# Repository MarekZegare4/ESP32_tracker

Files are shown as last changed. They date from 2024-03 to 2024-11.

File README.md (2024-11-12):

## Antenna tracker based on ESP32 microcontroller

This project focuses on the development of an antenna tracker with some ground station functionalities. Developed in platformio with Arduino framework. Based on [mLRS](https://github.com/olliw42/mLRS) project for MAVLink telemetry data.

### Contents of the repository
- `src` - source code of the project
- `schematic` - schematics and PCB design files
- `matlab_scripts` - magnetometer calibration routine

### Current features
- Tracking based on built-in GNSS receiver data and telemetry data from UAV
- 360° continuous rotation in vertical axis
- WiFi/BT/USB telemetry bridge
- Implemented magnetometer with calibration routine
### To be implemented
- GUI for configuration and monitoring on built-in display
- IMU pan and tilt stabilization
-
-
- More telemetry protocols

---

## Current PCB design
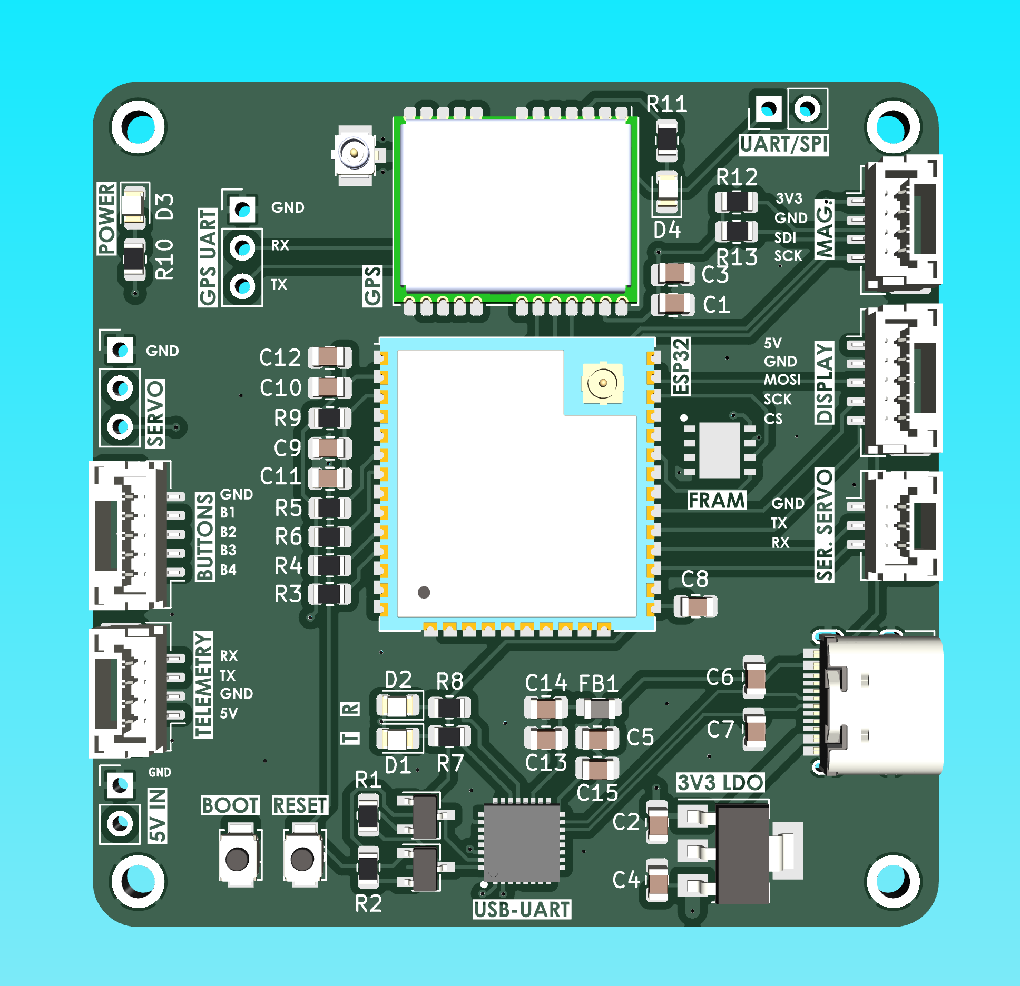
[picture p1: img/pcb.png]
PCB


## Current mechanical design
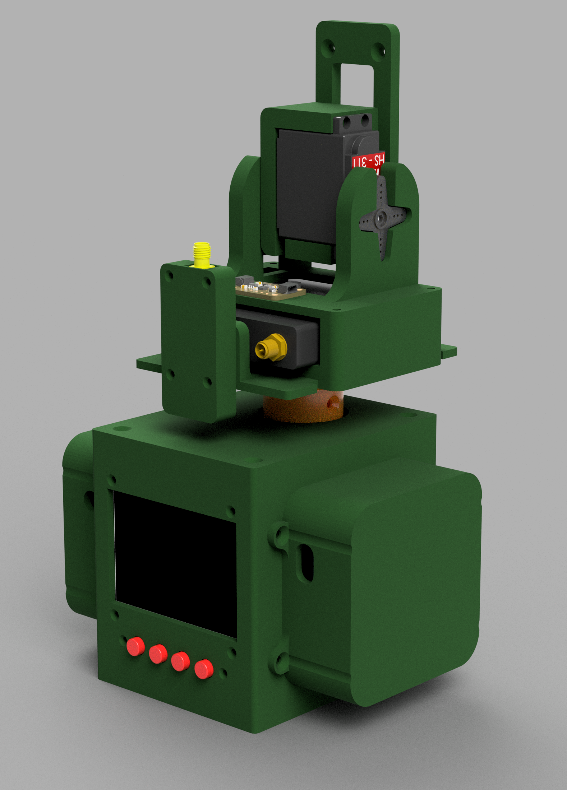
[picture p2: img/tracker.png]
Mechanical


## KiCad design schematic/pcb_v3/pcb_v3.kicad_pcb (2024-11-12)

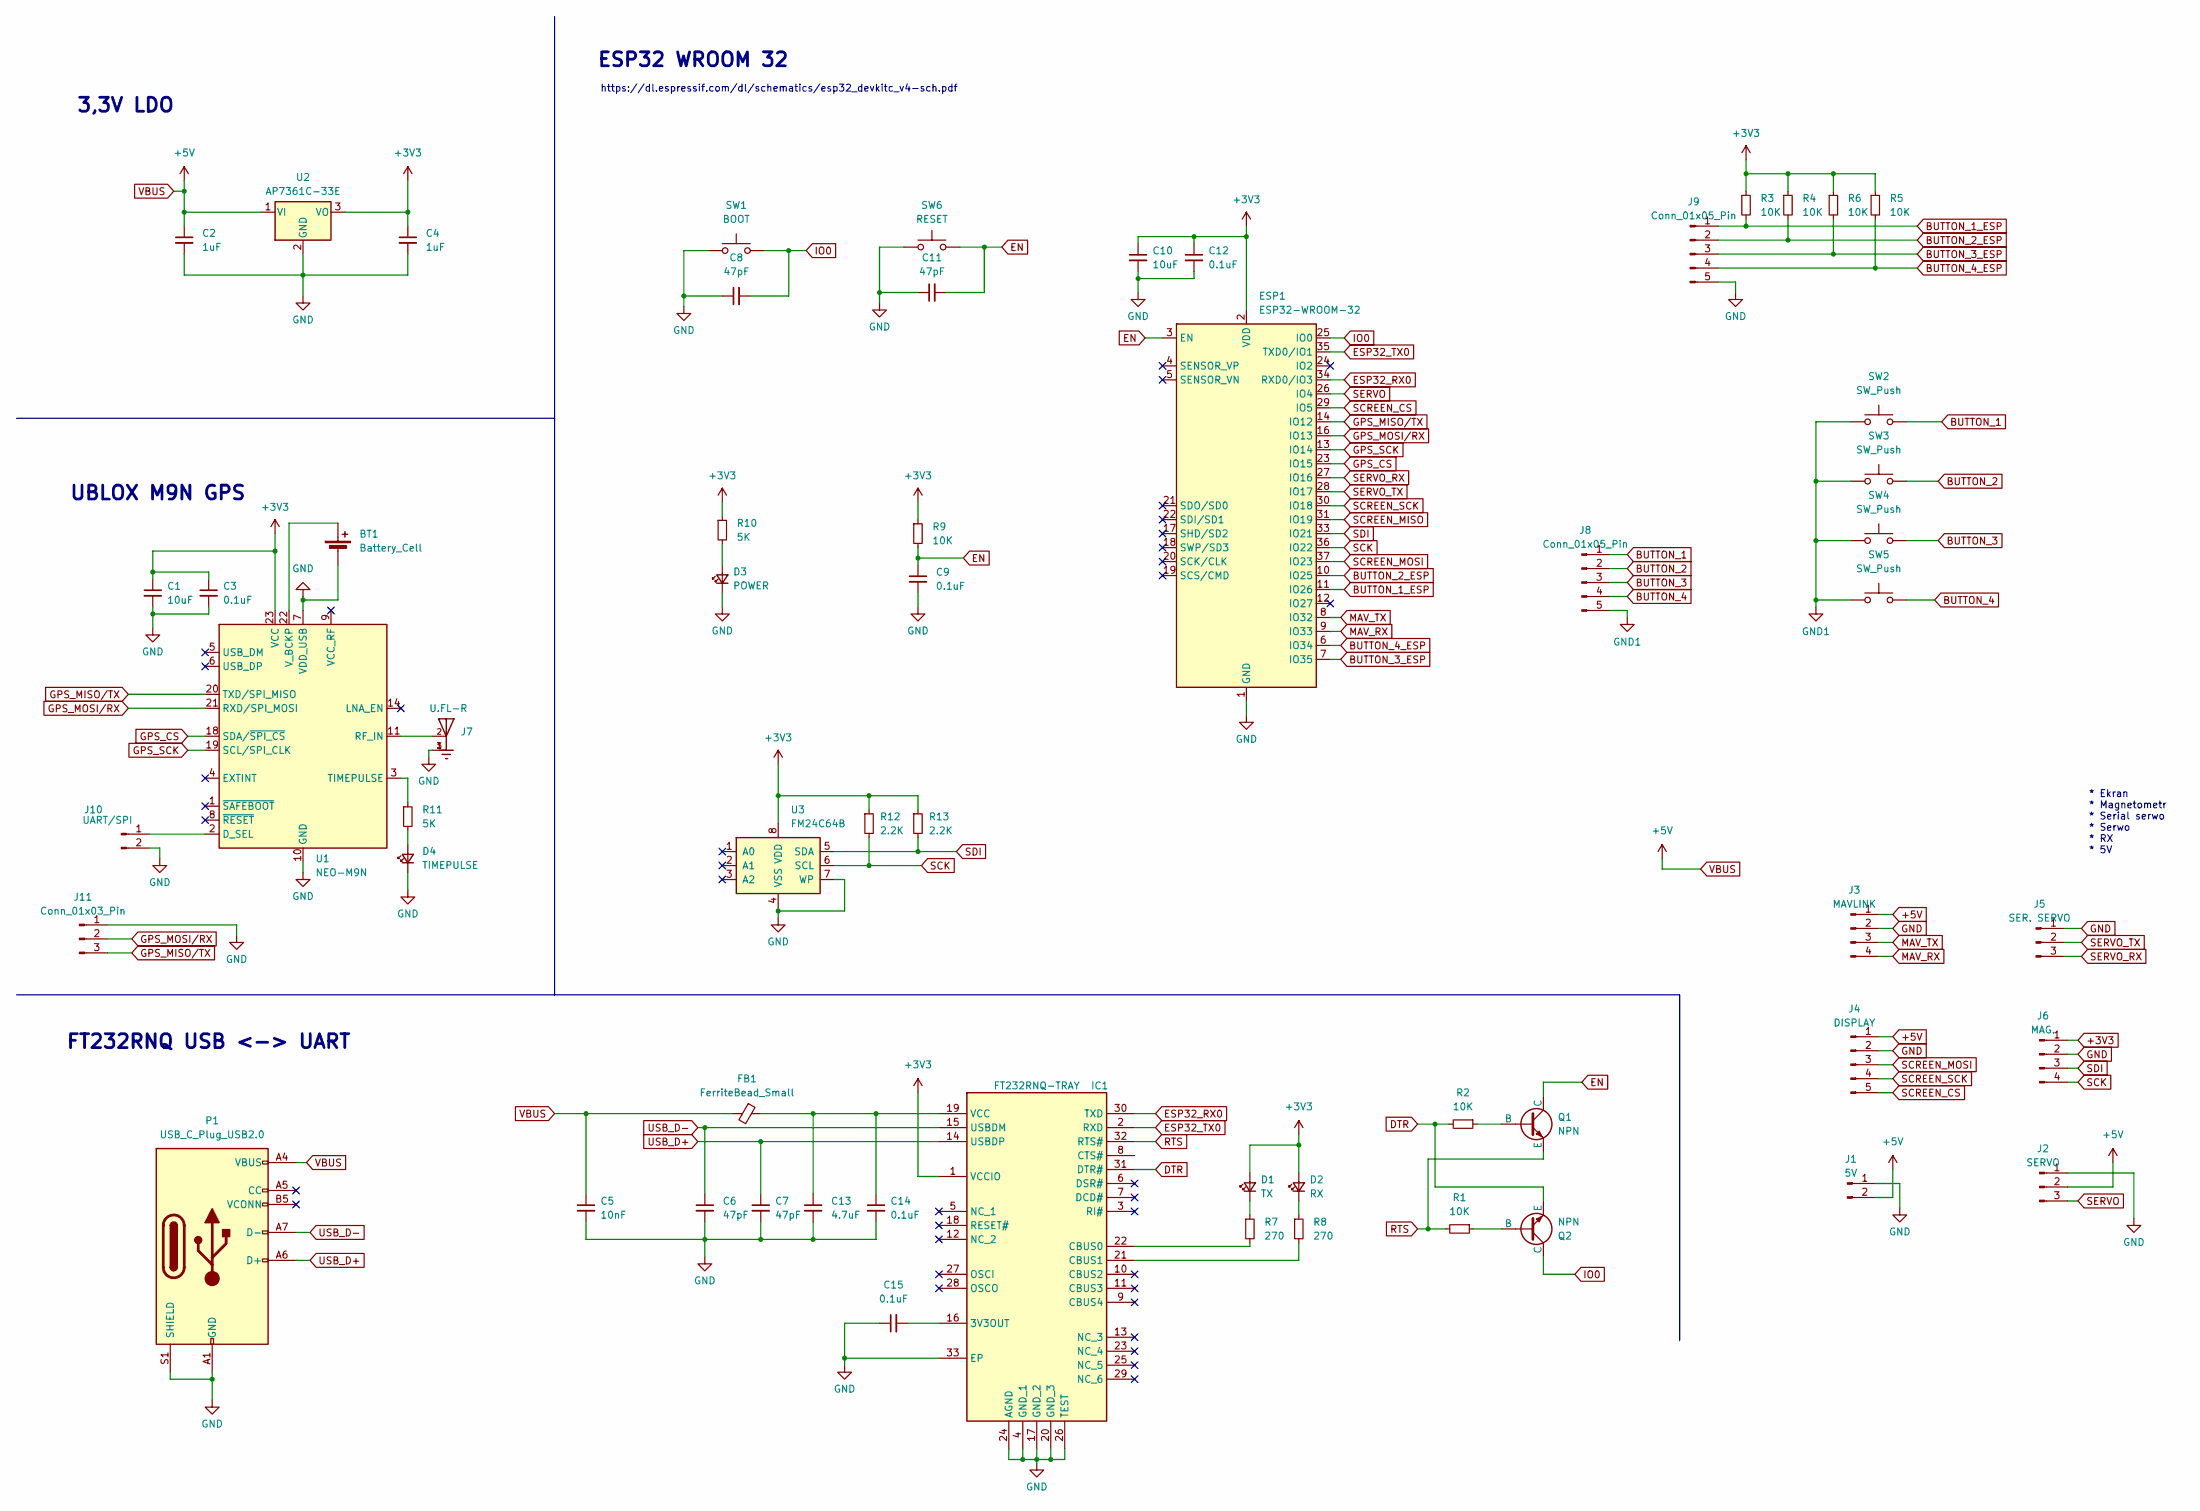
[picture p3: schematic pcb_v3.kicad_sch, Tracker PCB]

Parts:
BT1: Battery_Cell; BatteryHolder_Keystone_1060_1x2032
C1, C10: 10uF; C_0805_2012Metric
C2, C4: 1uF; C_0805_2012Metric
C3, C9, C12, C14, C15: 0.1uF; C_0805_2012Metric
C5: 10nF; C_0805_2012Metric
C6, C7, C8, C11: 47pF; C_0805_2012Metric
C13: 4.7uF; C_0805_2012Metric
D1: TX; LED_0805_2012Metric
D2: RX; LED_0805_2012Metric
D3: POWER; LED_0805_2012Metric
D4: TIMEPULSE; LED_0805_2012Metric
ESP1: ESP32-WROOM-32; ESP32-WROOM-32UE
FB1: FerriteBead_Small; L_0805_2012Metric
IC1: FT232RNQ-TRAY; QFN50P500X500X90-33N-D; Mouser Part Number 895-FT232RNQ-TRAY
J1: 5V; PinHeader_1x02_P2.54mm_Vertical
J2: SERVO; PinHeader_1x03_P2.54mm_Vertical
J3: MAVLINK; JST_GH_BM04B-GHS-TBT_1x04-1MP_P1.25mm_Vertical
J4: DISPLAY; JST_GH_BM05B-GHS-TBT_1x05-1MP_P1.25mm_Vertical
J5: SER. SERVO; JST_GH_BM03B-GHS-TBT_1x03-1MP_P1.25mm_Vertical
J6: MAG.; JST_GH_BM04B-GHS-TBT_1x04-1MP_P1.25mm_Vertical
J7: U.FL-R; HRS_U.FL-R-SMT-1(10)
J8: Conn_01x05_Pin; PinHeader_1x05_P1.27mm_Vertical_SMD_Pin1Left
J9: Conn_01x05_Pin; JST_GH_BM05B-GHS-TBT_1x05-1MP_P1.25mm_Vertical
J10: UART/SPI; PinHeader_1x02_P2.54mm_Vertical
J11: Conn_01x03_Pin; PinHeader_1x03_P2.54mm_Vertical
P1: USB_C_Plug_USB2.0; USB_C_Receptacle_HRO_TYPE-C-31-M-12
Q1, Q2: NPN; TSOT-23
R1, R2, R3, R4, R5, R6, R9: 10K; R_0805_2012Metric
R7, R8: 270; R_0805_2012Metric
R10, R11: 5K; R_0805_2012Metric
R12, R13: 2.2K; R_0805_2012Metric
SW1: BOOT; SW_SPST_B3U-1000P
SW2, SW3, SW4, SW5: SW_Push; SW_SPST_B3SL-1002P
SW6: RESET; SW_SPST_B3U-1000P
U1: NEO-M9N; ublox_NEO
U2: AP7361C-33E; SOT-223-3_TabPin2
U3: FM24C64B; SON95P400X450X80-9N

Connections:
+3V3: C1.1, C3.1, C4.1, C10.1, C12.1, D1.2 (A), D2.2 (A), ESP1.2 (VDD), IC1.1 (VCCIO), J6.1, R3.1, R4.1, R5.1, R6.1, R9.1, R10.1, R12.1, R13.1, U1.23 (VCC), U2.3 (VO), U3.8 (VDD)
+5V: C2.1, C5.1, FB1.2, J1.2, J2.2, J3.1, J4.1, P1.A4 (VBUS), P1.A9 (VBUS), P1.B4 (VBUS), P1.B9 (VBUS), U2.1 (VI)
BUTTON_1: J8.1, SW2.2
BUTTON_1_ESP: ESP1.11 (IO26), J9.1, R3.2
BUTTON_2: J8.2, SW3.2
BUTTON_2_ESP: ESP1.10 (IO25), J9.2, R4.2
BUTTON_3: J8.3, SW4.2
BUTTON_3_ESP: ESP1.7 (IO35), J9.3, R6.2
BUTTON_4: J8.4, SW5.2
BUTTON_4_ESP: ESP1.6 (IO34), J9.4, R5.2
DTR: IC1.31 (DTR#), Q2.3 (E), R2.2
EN: C9.1, C11.2, ESP1.3 (EN), Q1.1 (C), R9.2, SW6.2
ESP32_RX0: ESP1.34 (RXD0/IO3), IC1.30 (TXD)
ESP32_TX0: ESP1.35 (TXD0/IO1), IC1.2 (RXD)
GND: BT1.2 (-), C1.2, C2.2, C3.2, C4.2, C5.2, C6.2, C7.2, C8.1, C9.2, C10.2, C11.1, C12.2, C13.2, C14.2, C15.1, D3.1 (K), D4.1 (K), ESP1.1 (GND), ESP1.15 (GND), ESP1.38 (GND), ESP1.39 (GND), IC1.4 (GND_1), IC1.17 (GND_2), IC1.20 (GND_3), IC1.24 (AGND), IC1.26 (TEST), IC1.33 (EP), J1.1, J2.1, J3.2, J4.2, J5.1, J6.2, J7.1, J7.3, J9.5, J10.2, J11.1, P1.A1 (GND), P1.A12 (GND), P1.B1 (GND), P1.B12 (GND), P1.S1 (SHIELD), SW1.1, SW6.1, U1.7 (VDD_USB), U1.10 (GND), U1.12 (GND), U1.13 (GND), U1.24 (GND), U2.2 (GND), U3.4 (VSS), U3.7 (WP)
GND1: J8.5, SW2.1, SW3.1, SW4.1, SW5.1
GPS_CS: ESP1.23 (IO15), U1.18 (SDA/~SPI_CS)
GPS_MISO/TX: ESP1.14 (IO12), J11.3, U1.20 (TXD/SPI_MISO)
GPS_MOSI/RX: ESP1.16 (IO13), J11.2, U1.21 (RXD/SPI_MOSI)
GPS_SCK: ESP1.13 (IO14), U1.19 (SCL/SPI_CLK)
IO0: C8.2, ESP1.25 (IO0), Q2.1 (C), SW1.2
MAV_RX: ESP1.9 (IO33), J3.4
MAV_TX: ESP1.8 (IO32), J3.3
unnamed: BT1.1 (+), U1.22 (V_BCKP)
unnamed: D1.1 (K), R7.1
unnamed: D2.1 (K), R8.1
unnamed: D3.2 (A), R10.2
unnamed: D4.2 (A), R11.2
unnamed: C15.2, IC1.16 (3V3OUT)
unnamed: IC1.22 (CBUS0), R7.2
unnamed: IC1.21 (CBUS1), R8.2
unnamed: C13.1, C14.1, FB1.1, IC1.19 (VCC)
unnamed: J10.1, U1.2 (D_SEL)
unnamed: Q1.2 (B), R2.1
unnamed: Q2.2 (B), R1.1
unnamed: J7.2, U1.11 (RF_IN)
unnamed: R11.1, U1.3 (TIMEPULSE)
RTS: IC1.32 (RTS#), Q1.3 (E), R1.2
SCK: ESP1.36 (IO22), J6.4, R12.2, U3.6 (SCL)
SCREEN_CS: ESP1.29 (IO5), J4.5
SCREEN_MISO: ESP1.31 (IO19)
SCREEN_MOSI: ESP1.37 (IO23), J4.3
SCREEN_SCK: ESP1.30 (IO18), J4.4
SDI: ESP1.33 (IO21), J6.3, R13.2, U3.5 (SDA)
SERVO: ESP1.26 (IO4), J2.3
SERVO_RX: ESP1.27 (IO16), J5.3
SERVO_TX: ESP1.28 (IO17), J5.2
USB_D+: C7.1, IC1.14 (USBDP), P1.A6 (D+)
USB_D-: C6.1, IC1.15 (USBDM), P1.A7 (D-)

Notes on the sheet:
* Ekran * Magnetometr * Serial serwo * Serwo * RX * 5V
FT232RNQ USB <-> UART
https://dl.espressif.com/dl/schematics/esp32_devkitc_v4-sch.pdf
3,3V LDO
ESP32 WROOM 32
UBLOX M9N GPS

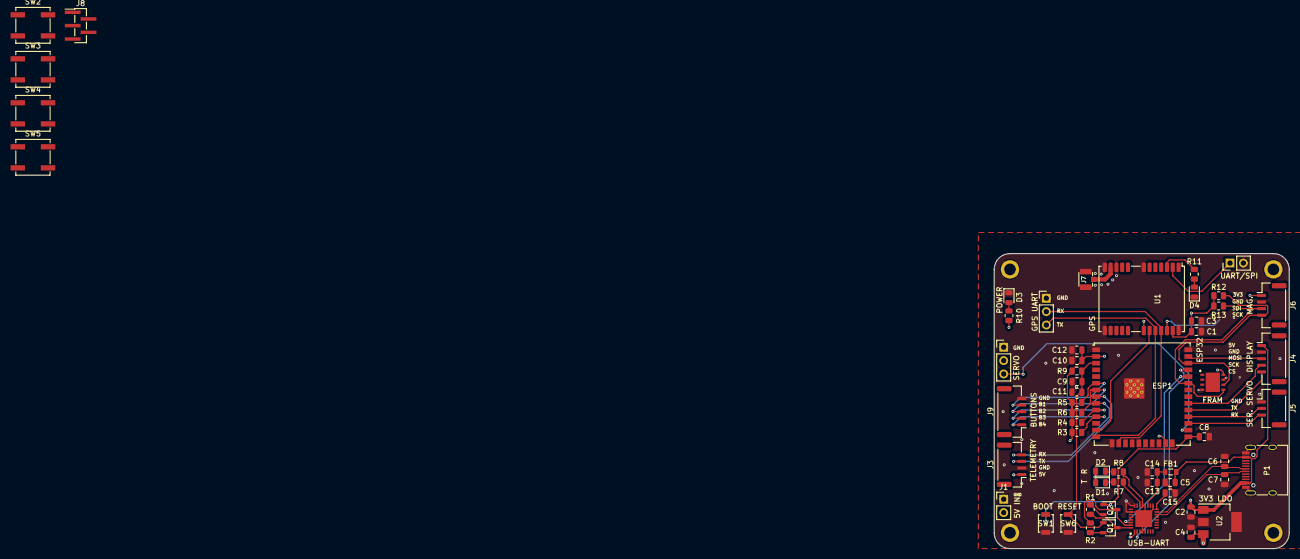
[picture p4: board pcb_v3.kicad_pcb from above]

Board: 4 copper layers, 56.0 x 56.0 mm, 59 parts (1 on the bottom side), 48 nets.

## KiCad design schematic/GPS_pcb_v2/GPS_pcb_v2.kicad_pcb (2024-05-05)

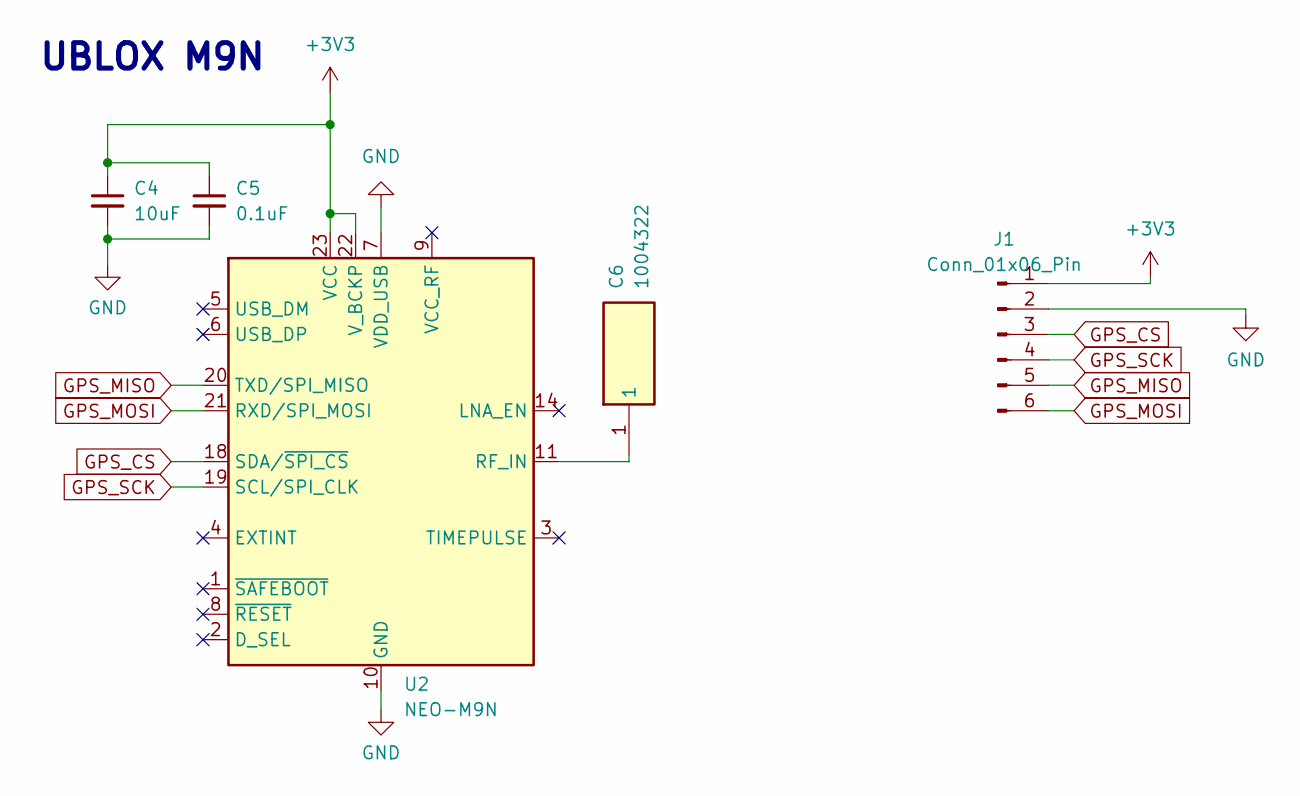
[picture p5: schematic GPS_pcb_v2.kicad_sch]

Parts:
C4: 10uF; C_0805_2012Metric
C5: 0.1uF; C_0805_2012Metric
C6: 1004322; GPS_ANTENNA; Mouser Part Number 581-1004322
J1: Conn_01x06_Pin; JST_GH_BM06B-GHS-TBT_1x06-1MP_P1.25mm_Vertical
U2: NEO-M9N; ublox_NEO

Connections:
+3V3: C4.1, C5.1, J1.1, U2.22 (V_BCKP), U2.23 (VCC)
GND: C4.2, C5.2, J1.2, U2.7 (VDD_USB), U2.10 (GND), U2.12 (GND), U2.13 (GND), U2.24 (GND)
GPS_CS: J1.3, U2.18 (SDA/~SPI_CS)
GPS_MISO: J1.5, U2.20 (TXD/SPI_MISO)
GPS_MOSI: J1.6, U2.21 (RXD/SPI_MOSI)
GPS_SCK: J1.4, U2.19 (SCL/SPI_CLK)
unnamed: C6.1, U2.11 (RF_IN)

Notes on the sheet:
UBLOX M9N

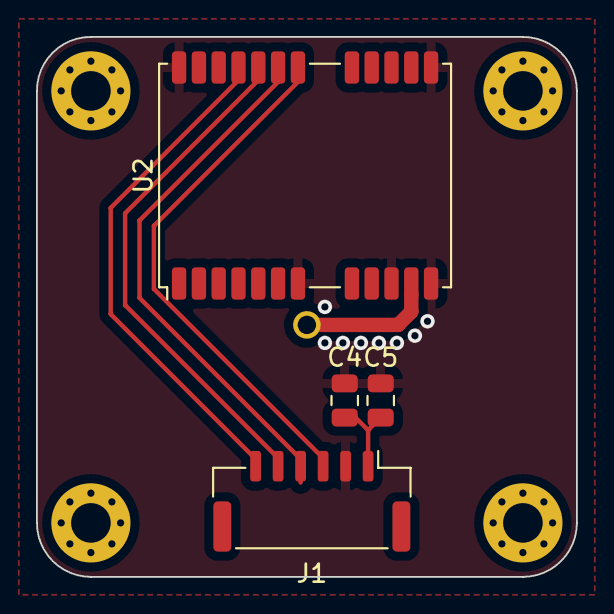
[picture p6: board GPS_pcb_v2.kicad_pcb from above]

Board: 2 copper layers, 30.0 x 30.0 mm, 5 parts (1 on the bottom side), 7 nets.

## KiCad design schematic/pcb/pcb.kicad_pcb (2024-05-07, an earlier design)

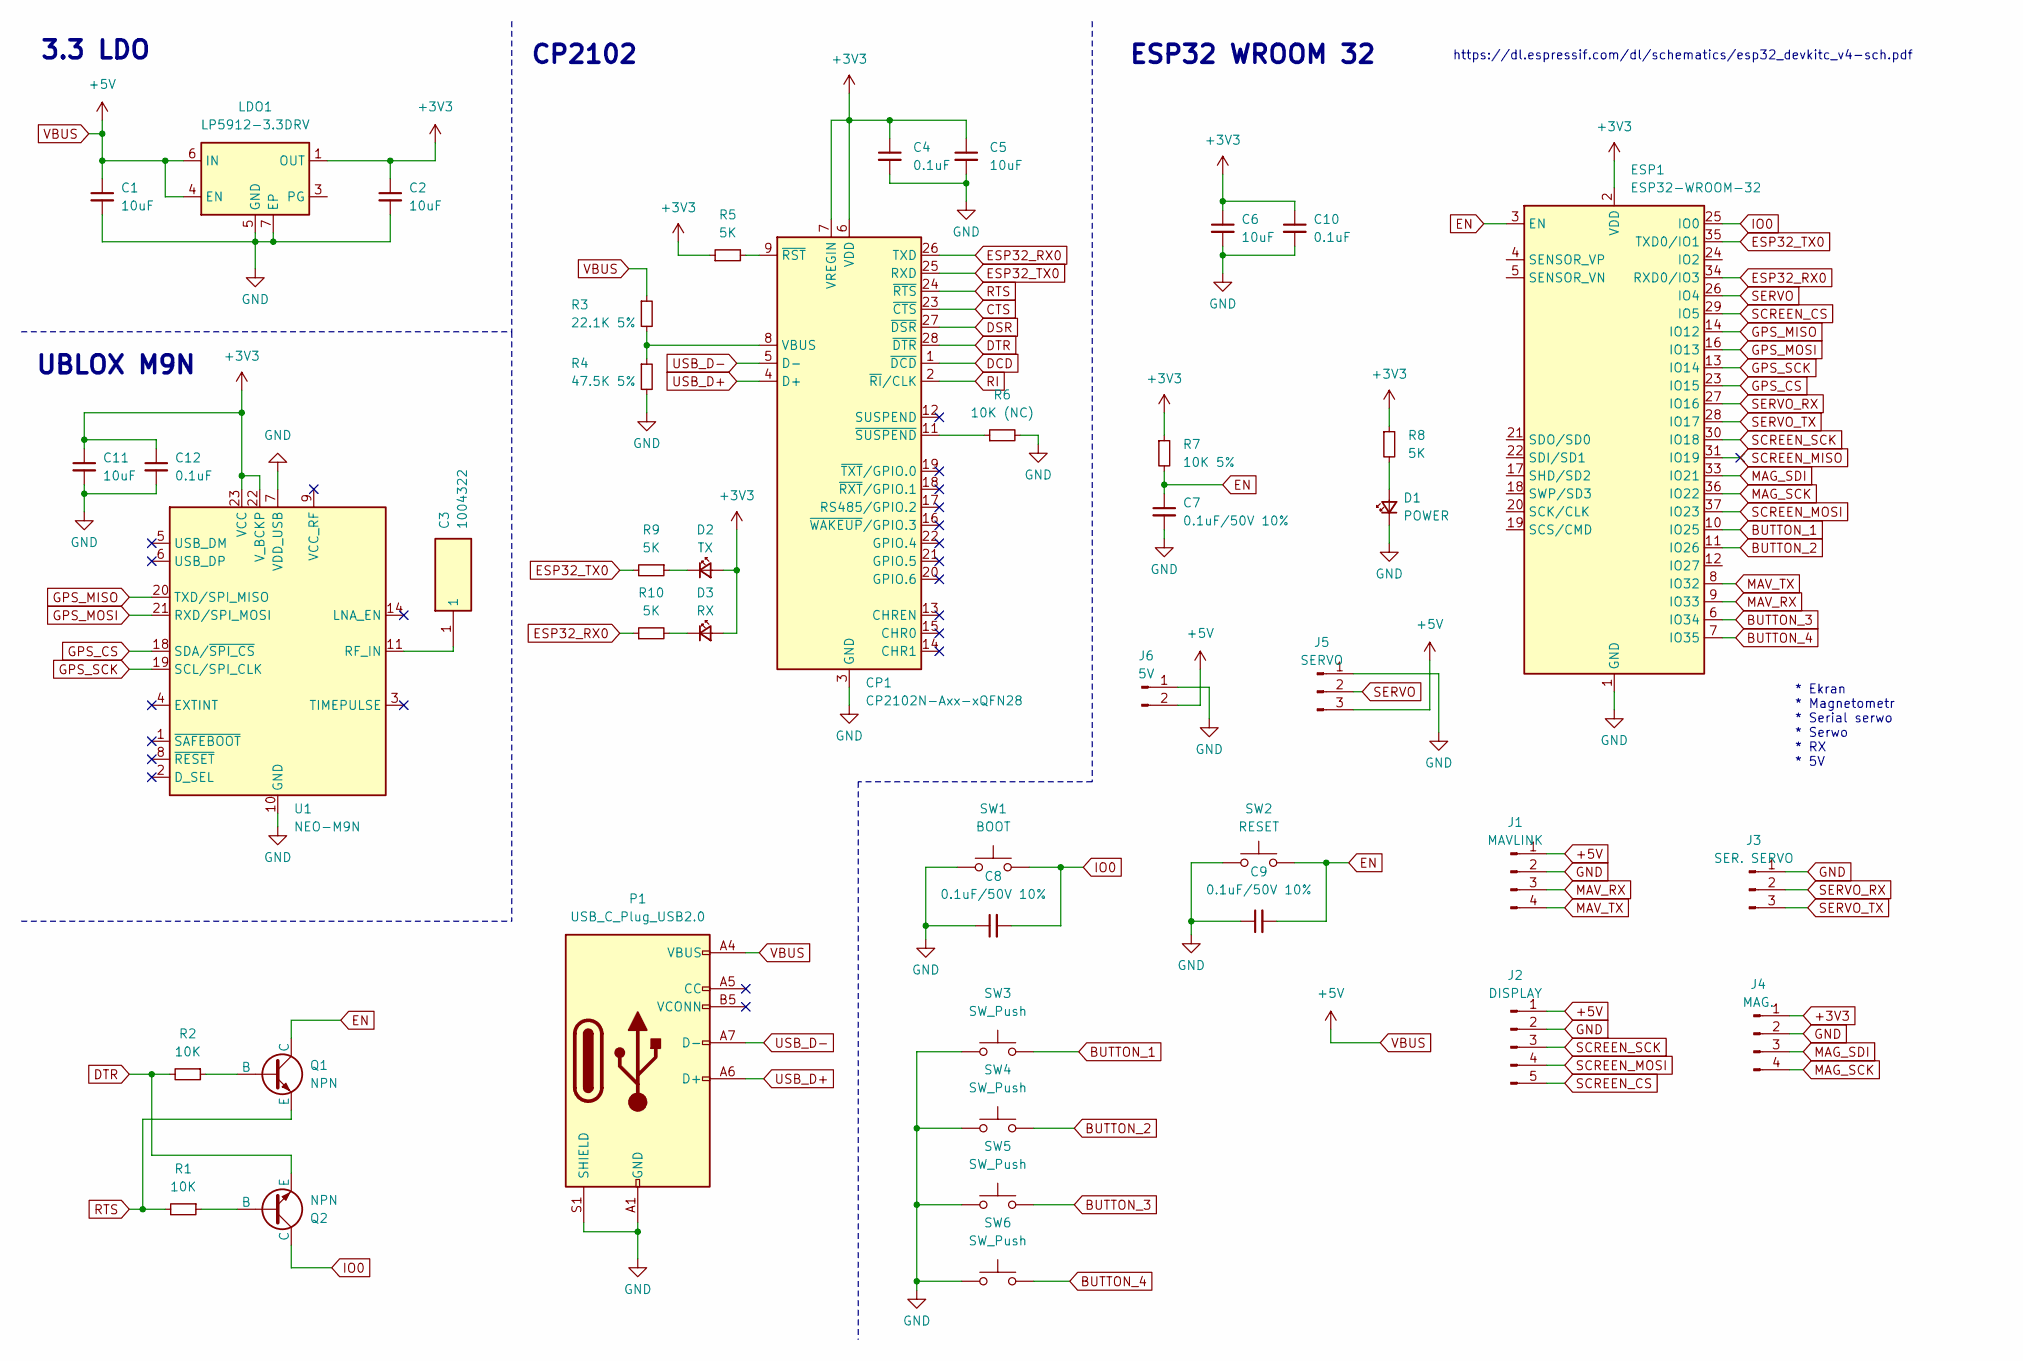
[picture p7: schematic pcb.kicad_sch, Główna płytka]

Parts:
C1, C2, C5, C6, C11: 10uF; C_0805_2012Metric
C3: 1004322; GPS_ANTENNA; Mouser Part Number 581-1004322
C4, C10, C12: 0.1uF; C_0805_2012Metric
C7, C8, C9: 0.1uF/50V 10%; C_0805_2012Metric
CP1: CP2102N-Axx-xQFN28; QFN-28-1EP_5x5mm_P0.5mm_EP3.35x3.35mm
D1: POWER; LED_0805_2012Metric
D2: TX; LED_0805_2012Metric
D3: RX; LED_0805_2012Metric
ESP1: ESP32-WROOM-32
J1: MAVLINK; JST_GH_BM04B-GHS-TBT_1x04-1MP_P1.25mm_Vertical
J2: DISPLAY; JST_GH_BM05B-GHS-TBT_1x05-1MP_P1.25mm_Vertical
J3: SER. SERVO; JST_GH_BM03B-GHS-TBT_1x03-1MP_P1.25mm_Vertical
J4: MAG.; JST_GH_BM04B-GHS-TBT_1x04-1MP_P1.25mm_Vertical
J5: SERVO; PinHeader_1x03_P2.54mm_Vertical
J6: 5V; PinHeader_1x02_P2.54mm_Vertical
LDO1: LP5912-3.3DRV; WSON-6-1EP_2x2mm_P0.65mm_EP1x1.6mm_ThermalVias
P1: USB_C_Plug_USB2.0; USB_C_Receptacle_HRO_TYPE-C-31-M-12
Q1, Q2: NPN; TSOT-23
R1, R2: 10K; R_0805_2012Metric
R3: 22.1K 5%; R_0805_2012Metric
R4: 47.5K 5%; R_0805_2012Metric
R5, R8, R9, R10: 5K; R_0805_2012Metric
R6: 10K (NC); R_0805_2012Metric
R7: 10K 5%; R_0805_2012Metric
SW1: BOOT; SW_SPST_B3U-1000P
SW2: RESET; SW_SPST_B3U-1000P
SW3, SW4, SW5, SW6: SW_Push; SW_SPST_B3SL-1002P
U1: NEO-M9N; ublox_NEO

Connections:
+3V3: C2.1, C4.1, C5.1, C6.1, C10.1, C11.1, C12.1, CP1.6 (VDD), CP1.7 (VREGIN), D2.2 (A), D3.2 (A), ESP1.2 (VDD), J4.1, LDO1.1 (OUT), R5.1, R7.1, R8.1, U1.22 (V_BCKP), U1.23 (VCC)
+5V: C1.1, J1.1, J2.1, J5.3, J6.2, LDO1.4 (EN), LDO1.6 (IN), P1.A4 (VBUS), P1.A9 (VBUS), P1.B4 (VBUS), P1.B9 (VBUS), R3.1
BUTTON_1: ESP1.10 (IO25), SW3.2
BUTTON_2: ESP1.11 (IO26), SW4.2
BUTTON_3: ESP1.6 (IO34), SW5.2
BUTTON_4: ESP1.7 (IO35), SW6.2
CTS: CP1.23 (~CTS)
DCD: CP1.1 (~DCD)
DSR: CP1.27 (~DSR)
DTR: CP1.28 (~DTR), Q2.3 (E), R2.2
EN: C7.1, C9.2, ESP1.3 (EN), Q1.1 (C), R7.2, SW2.2
ESP32_RX0: CP1.26 (TXD), ESP1.34 (RXD0/IO3), R10.1
ESP32_TX0: CP1.25 (RXD), ESP1.35 (TXD0/IO1), R9.2
GND: C1.2, C2.2, C4.2, C5.2, C6.2, C7.2, C8.1, C9.1, C10.2, C11.2, C12.2, CP1.3 (GND), CP1.29 (GND), D1.1 (K), ESP1.1 (GND), ESP1.15 (GND), ESP1.38 (GND), ESP1.39 (GND), J1.2, J2.2, J3.1, J4.2, J5.1, J6.1, LDO1.5 (GND), LDO1.7 (EP), P1.A1 (GND), P1.A12 (GND), P1.B1 (GND), P1.B12 (GND), P1.S1 (SHIELD), R4.2, R6.2, SW1.1, SW2.1, SW3.1, SW4.1, SW5.1, SW6.1, U1.7 (VDD_USB), U1.10 (GND), U1.12 (GND), U1.13 (GND), U1.24 (GND)
GPS_CS: ESP1.23 (IO15), U1.18 (SDA/~SPI_CS)
GPS_MISO: ESP1.14 (IO12), U1.20 (TXD/SPI_MISO)
GPS_MOSI: ESP1.16 (IO13), U1.21 (RXD/SPI_MOSI)
GPS_SCK: ESP1.13 (IO14), U1.19 (SCL/SPI_CLK)
IO0: C8.2, ESP1.25 (IO0), Q2.1 (C), SW1.2
MAG_SCK: ESP1.36 (IO22), J4.4
MAG_SDI: ESP1.33 (IO21), J4.3
MAV_RX: ESP1.9 (IO33), J1.3
MAV_TX: ESP1.8 (IO32), J1.4
unnamed: CP1.8 (VBUS), R3.2, R4.1
unnamed: CP1.9 (~RST), R5.2
unnamed: CP1.11 (~SUSPEND), R6.1
unnamed: D1.2 (A), R8.2
unnamed: D2.1 (K), R9.1
unnamed: D3.1 (K), R10.2
unnamed: Q1.2 (B), R2.1
unnamed: Q2.2 (B), R1.1
unnamed: C3.1, U1.11 (RF_IN)
RI: CP1.2 (~RI/CLK)
RTS: CP1.24 (~RTS), Q1.3 (E), R1.2
SCREEN_CS: ESP1.29 (IO5), J2.5
SCREEN_MISO: ESP1.31 (IO19)
SCREEN_MOSI: ESP1.37 (IO23), J2.4
SCREEN_SCK: ESP1.30 (IO18), J2.3
SERVO: ESP1.26 (IO4), J5.2
SERVO_RX: ESP1.27 (IO16), J3.2
SERVO_TX: ESP1.28 (IO17), J3.3
USB_D+: CP1.4 (D+), P1.A6 (D+)
USB_D-: CP1.5 (D-), P1.A7 (D-)

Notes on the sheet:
CP2102
* Ekran * Magnetometr * Serial serwo * Serwo * RX * 5V
https://dl.espressif.com/dl/schematics/esp32_devkitc_v4-sch.pdf
UBLOX M9N
ESP32 WROOM 32
3.3 LDO

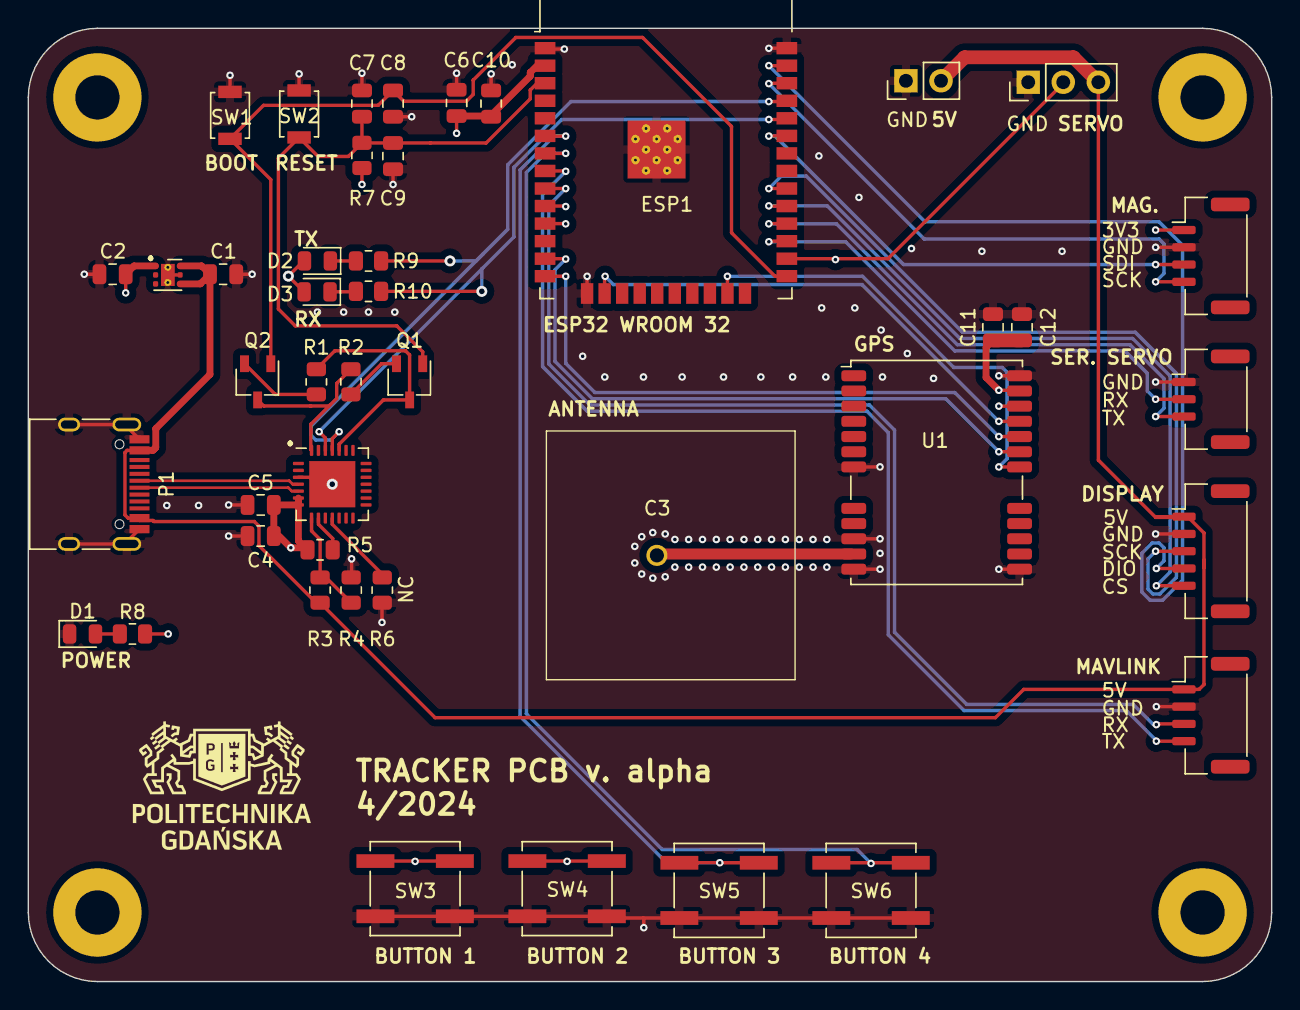
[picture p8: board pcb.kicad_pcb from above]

Board: 4 copper layers, 90.0 x 69.0 mm, 44 parts (0 on the bottom side), 38 nets.

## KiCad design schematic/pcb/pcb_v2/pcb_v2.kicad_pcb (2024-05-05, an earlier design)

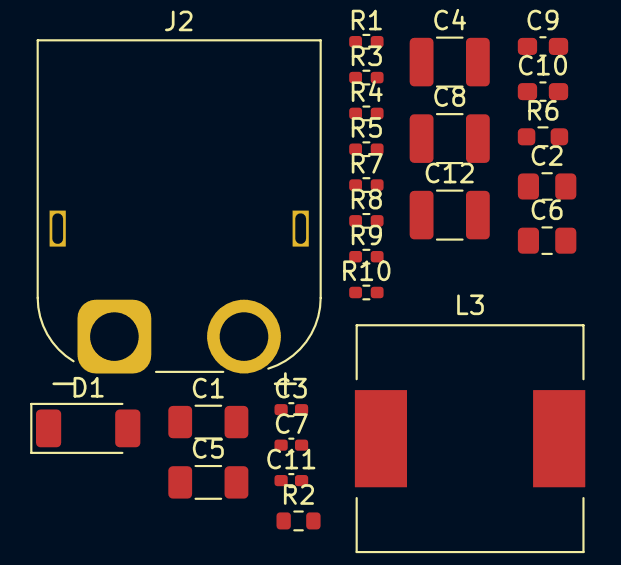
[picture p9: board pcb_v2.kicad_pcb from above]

Board: 2 copper layers, 25 parts (0 on the bottom side), 10 nets, no tracks yet.

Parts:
C1, C5: 4.7uF; C_1206_3216Metric_Pad1.33x1.80mm_HandSolder
C2, C6: 100nF; C_0805_2012Metric_Pad1.18x1.45mm_HandSolder
C3, C7, C11: 100nF; C_0402_1005Metric_Pad0.74x0.62mm_HandSolder
C4: 100uF; C_1210_3225Metric_Pad1.33x2.70mm_HandSolder
C8, C12: 47uF; C_1210_3225Metric_Pad1.33x2.70mm_HandSolder
C9: 4.7uF; C_0603_1608Metric_Pad1.08x0.95mm_HandSolder
C10: 100nF; C_0603_1608Metric_Pad1.08x0.95mm_HandSolder
D1: D_Small; D_SOD-128
J2: XT60PW-M; AMASS_XT60PW-M_1x02_P7.20mm_Horizontal
L3: 15uH; L_12x12mm_H8mm
R1: 18.7k; R_0402_1005Metric_Pad0.72x0.64mm_HandSolder
R2: 100k; R_0603_1608Metric
R3, R7: 100k; R_0402_1005Metric_Pad0.72x0.64mm_HandSolder
R4: 32k; R_0402_1005Metric_Pad0.72x0.64mm_HandSolder
R5: 13.3k; R_0402_1005Metric_Pad0.72x0.64mm_HandSolder
R6: 100k; R_0603_1608Metric_Pad0.98x0.95mm_HandSolder
R8: 19.1k; R_0402_1005Metric_Pad0.72x0.64mm_HandSolder
R9: 422k; R_0402_1005Metric_Pad0.72x0.64mm_HandSolder
R10: 22.1k; R_0402_1005Metric_Pad0.72x0.64mm_HandSolder

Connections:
3V3_FB: R3.2, R4.1
5V_FB: R7.2, R8.1
12V_SW: C11.2, L3.1
+3V3: C4.1, R2.2, R3.1
+5V: C8.1, R6.2, R7.1
+12V: C12.2, L3.2, R9.1
+24V: C1.1, C2.1, C5.1, C6.1, C9.1, C10.1, D1.1 (K)
/FB_12V: R9.2, R10.1
GND: C1.2, C2.2, C4.2, C5.2, C6.2, C8.2, C9.2, C10.2, C12.1, J2.1, R1.2, R4.2, R5.2, R8.2, R10.2
unnamed: D1.2 (A), J2.2

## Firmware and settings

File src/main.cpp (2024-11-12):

#include <Arduino.h>
#include "tracking/tracking.h"
#include "gui/gui.h"
#include "mavlink/mav.h"

void setup()
{
  Serial.begin(115200);
  trackingInitialize();   // Servo and IMU initialization
  mavlinkInit();          // MAVLink comm initialization
  guiInitialize();        // GUI initialization
  xTaskCreate(trackingTask, "Movement and stabilization", 2048, NULL, 1, NULL);
  xTaskCreate(guiTask, "GUI", 4096, NULL, 1, NULL);
  xTaskCreate(decodeTelemetryTask, "Telemetry decoding", 4096, NULL, 1, NULL);
}

void loop()
{
  vTaskDelete(NULL);
}

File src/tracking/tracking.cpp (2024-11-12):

#include <Arduino.h>
#include <SCServo.h>
#include <Wire.h>
#include <SPI.h>
#include <Adafruit_LIS3MDL.h>
#include <Adafruit_LSM6DS3TRC.h>
#include <Adafruit_Sensor.h>
#include <ESP32Servo.h>
#include <SparkFun_u-blox_GNSS_v3.h>
#include <WMM_Tinier.h>
#include "gui/gui.h"
#include "mavlink/mav.h"
#include "tracking.h"
#include "tracking/geoTransform/geoTransform.h"
#include "imu_calibration/imu_calibration.h"

// https://www.waveshare.com/wiki/ST3020_Servo#Overview

#define SERVO_RX 16
#define SERVO_TX 17
#define SERVO_TILT_PIN 4
#define myCS 15              // Define the GPIO pin number for the SPI Chip Select. Change this if required
#define myClockSpeed 1000000 // Define what SPI clock speed to use. Change this if required

Servo servo;
SMS_STS st;
Adafruit_LIS3MDL lis3mdl;
Adafruit_LSM6DS3TRC lsm6ds3trc;
SFE_UBLOX_GNSS_SPI myGNSS; // SFE_UBLOX_GNSS_SPI uses SPI. For I2C or Serial, see Example1 and Example2
WMM_Tinier declination;
SPIClass spiPort(HSPI);
TrackerDataGPS gpsData;

AngleValues sDistAziElev;
float sCompassDegree;

float getCompassDegree()
{
  return sCompassDegree;
}

void trackingInitialize()
{
  Serial1.begin(1000000, SERIAL_8N1, SERVO_RX, SERVO_TX);
  declination.begin();
  st.pSerial = &Serial1;
  ESP32PWM::allocateTimer(0);
  ESP32PWM::allocateTimer(1);
  ESP32PWM::allocateTimer(2);
  ESP32PWM::allocateTimer(3);
  servo.setPeriodHertz(50);                 // Standard 50hz servo
  servo.attach(SERVO_TILT_PIN, 1000, 2000); // attaches the servo on pin 4 to the servo object
  servo.write(0);
  lis3mdl.begin_I2C();
  lis3mdl.setRange(LIS3MDL_RANGE_4_GAUSS);
  lis3mdl.setDataRate(LIS3MDL_DATARATE_5_HZ);
  lsm6ds3trc.begin_I2C();
  while (myGNSS.begin(spiPort, myCS, myClockSpeed) == false) // Connect to the u-blox module using the port, chip select pin and speed defined above
  {
    delay(1000);
  }
  myGNSS.setSPIOutput(COM_TYPE_UBX); // Set the SPI port to output UBX only (turn off NMEA noise)
  myGNSS.setNavigationFrequency(5);  // Set the update rate to 10Hz
}

int angleToServo(int angle)
{
  return 4096 / 360 * angle;
}

void servoDemo()
{
  st.WritePosEx(1, 2048, 1500);
  servo.write(45);
  delay(1000);
  st.WritePosEx(1, -2048, 1500);
  servo.write(0);
  delay(1000);
}

int readCurrent()
{
  return st.ReadCurrent(1);
}

TrackerDataGPS getTrackerGPS()
{
  return gpsData;
}

sensor_t sensor;
float x, y, z;
int i = 0;
void trackingTask(void *parameters)
{
  for (;;)
  {
    // Read data from GNSS module
    if (myGNSS.getPVT() == true)
    {
      gpsData.latitude = myGNSS.getLatitude();
      gpsData.longitude = myGNSS.getLongitude();
      gpsData.altitude = myGNSS.getAltitudeMSL(); // Altitude above Mean Sea Level
      gpsData.fixType = myGNSS.getFixType();
      gpsData.satCount = myGNSS.getSIV();
    }

    Wgs84Coord trackerPos;
    Wgs84Coord uavPos;
    AngleValues angles;
    // Update the tracker and UAV positions
    trackerPos.lat = gpsData.latitude;
    trackerPos.lon = gpsData.longitude;
    trackerPos.alt = gpsData.altitude;

    uavPos.alt = getUavGPS()->global_lat;
    uavPos.lon = getUavGPS()->global_lon;
    uavPos.alt = getUavGPS()->global_alt;

    // Calculate the magnetic declination
    float dec = declination.magneticDeclination(trackerPos.lat, trackerPos.lon, myGNSS.getYear(), myGNSS.getMonth(), myGNSS.getDay());

    angles = DistAziElev(trackerPos, uavPos);
    gpsData.angles = angles;

    sensors_event_t mag;
    sensors_event_t accel;
    sensors_event_t gyro;
    sensors_event_t temp;

    lis3mdl.getEvent(&mag);
    lsm6ds3trc.getEvent(&accel, &gyro, &temp);
    // CalibratedMagData data = calibratedData(mag.magnetic.x, mag.magnetic.y, mag.magnetic.z);
    // Serial.print(String(data.x) + " " + String(data.y) + " " + String(data.z) + ";" + "\n");
    Serial.print(String(accel.acceleration.x) + " " + String(accel.acceleration.y) + " " + String(accel.acceleration.z) + ";" + "\n");

    vTaskDelay(100 / portTICK_PERIOD_MS);
  }
}

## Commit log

2024-01-10 change esp board
2024-03-05 pcb #2
    [pcb.kicad_sch]
2024-03-06 schematic update
    [pcb.kicad_pcb, pcb.kicad_sch]
2024-03-08 schematic udpt
    [pcb.kicad_sch]
2024-03-08 ldo added
    [pcb.kicad_sch]
2024-03-18 split files, print on screen
2024-03-26 pcb updt
    [pcb.kicad_pcb]
2024-03-26 pcb update
    [pcb.kicad_pcb, pcb.kicad_sch]
2024-04-02 trzymam kciuki
    [pcb.kicad_pcb, pcb.kicad_sch]
2024-04-03 lets go
    [pcb.kicad_pcb, pcb.kicad_sch]
2024-04-11 new pcb
    [pcb.kicad_pcb, pcb.kicad_sch]
2024-04-12 board update
    [pcb.kicad_pcb]
2024-04-12 v. alpha pcb
    [pcb.kicad_sch]
2024-04-12 v. alpha pcb 2
    [pcb.kicad_pcb]
2024-04-13 pcb v3
    [pcb.kicad_pcb, pcb.kicad_sch]
2024-04-13 added leds
    [pcb.kicad_pcb]
2024-04-13 pcb final v1
    [pcb.kicad_pcb]
2024-04-23 inventor model, geotransform coeff param
    [Assembly1.0013.iam, Assembly1.iam, Bearing1.iam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]
2024-05-05 gps tweaks
    [GPS_pcb_v2.kicad_pcb, GPS_pcb_v2.kicad_sch, pcb.kicad_pcb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]
2024-05-07 button tests
    [pcb.kicad_pcb]
2024-05-10 pcb v beta, gui update
    [pcb_v2.kicad_pcb, pcb_v2.kicad_sch, pcb_v3.kicad_pcb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]
2024-05-11 pcb update, bluetooth bridge working
    [pcb_v3.kicad_pcb, pcb_v3.kicad_sch]
2024-06-12 pcb updates
    [pcb_v3.kicad_pcb, pcb_v3.kicad_sch]
2024-06-12 minor cleanup
    [Assembly1.0013.iam, Assembly1.iam, Bearing1.iam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]
2024-06-17 status screen
    [pcb_v3.kicad_pcb]
2024-09-02 menu framework, readme update
2024-09-21 serial servo test, added library for geomagnetic declination calculation
2024-09-26 pcb bad via, tests
    [pcb_v3.kicad_pcb]
2024-10-10 fram, gps uart
    [pcb_v3.kicad_pcb, pcb_v3.kicad_sch]
2024-10-10 pcb cleanup
    [pcb_v3.kicad_pcb, pcb_v3.kicad_sch]
2024-10-16 final pcb please
    [pcb_v3.kicad_pcb, pcb_v3.kicad_sch]
2024-10-27 updates, geotransform formula fix
    [tracking.cpp]
2024-11-12 magnetometer interface, cleanup
    [pcb_v3.kicad_pcb, pcb_v3.kicad_sch]
2024-11-12 acc correction matrices, calibration script
    [imu_calibration.cpp, tracking.cpp]
